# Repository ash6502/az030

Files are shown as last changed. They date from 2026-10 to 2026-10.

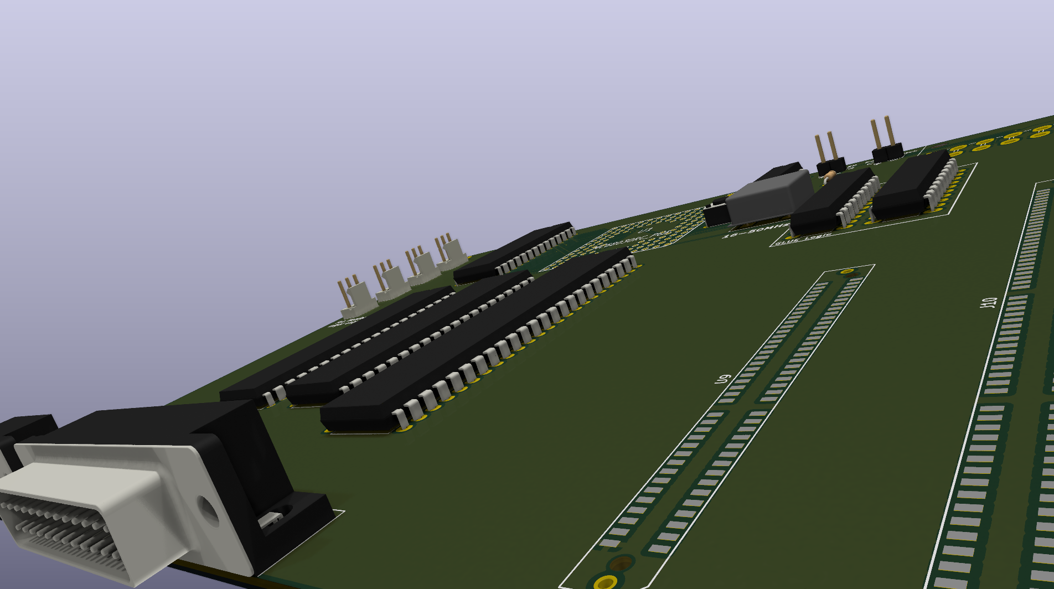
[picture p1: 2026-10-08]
kicad/main/exp2.png

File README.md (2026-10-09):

# az030 - a 68030-based homebrew computer
**! AI DISCLAIMER !**

Claude Code was used in the creation of this

# info

| Plan item | Status |
|---|---|
| 16–50 MHz clock | CPU clock generated in FPGA (25 MHz from a 50 MHz osc) |
| 128 MB – 1 GB RAM | 32 KB BRAM stand-in; SDRAM/DDR controller is next |
| Glue logic in FPGA | bus bridge, address decode, reset, UART, sysctrl |
| Video in FPGA | Address space reserved (VRAM `0xFD000000`, regs `0xFE003000`) |
| SCSI | Address space reserved (`0xFE002000`) |
| UNIX-like OS | Needs MMU → the 68030 (not 68EC030) was chosen for this |

## Memory map
| Address | Size | What |
|---|---|---|
| `0x0000_0000`  | 32 KB* | RAM (*for now). ROM overlays it at reset until SYSCTRL BOOT is written |
| `0xFD00_0000`  | – | VRAM (reserved) |
| `0xFE00_0000`  | 8 B | UART: `+0` DATA, `+4` STATUS (bit0 tx_ready, bit1 rx_valid) |
| `0xFE00_1000`  | 12 B | SYSCTRL: `+0` BOOT (any write drops overlay), `+4` ID, `+8` LEDS |
| `0xFE00_2000`  | – | SCSI (reserved) |
| `0xFE00_3000`  | – | Video registers (reserved) |
| `0xFFF0_0000`  | 16 KB  | Boot ROM (mirrored across 1 MB) |

Peripheral registers are **32-bit access only** (`move.l`). Unmapped addresses raise a bus error after 256 FPGA clocks.

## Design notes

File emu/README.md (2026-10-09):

# az030 emulator

An emulator for the az030 built on [m68k-rs](https://github.com/benletchford/m68k-rs).
It emulates a 68030 with an FPU (68881/68882), the memory map in `../MEM_MAP.md`, the UART
as your terminal, and an optional virtual SCSI bus.

```sh
cargo run --release                      # uses ./az030.toml
cargo run --release -- -c other.toml -v  # -v reports LED changes on stderr
cargo run --release -- --trace 200       # print the last 200 instructions (outside ROM) on exit
```

The UART connects to the terminal. **Ctrl-] q** quits, **Ctrl-] r** resets the machine, and
**Ctrl-] Ctrl-]** sends a literal Ctrl-]. Ctrl-C goes to the guest.

## Config (`az030.toml`)

| Key | Meaning |
|---|---|
| `machine.ram_size` | `"32K"`, `"128M"`, `"1G"`, or bytes. 4K–1G |
| `machine.clock_mhz` | Emulated clock, used to pace emulation (default 25) |
| `machine.throttle` | `false` runs as fast as possible |
| `machine.sysctrl_id` | Value of the SYSCTRL ID register (default `0x415A3330`, "AZ30") |
| `rom.file` | Raw boot ROM image, up to 1 MB, mirrored over `0xFFF00000+` |
| `scsi.enabled` | `false` leaves `0xFE002000` unmapped (bus error) |
| `timer.enabled` | `false` leaves `0xFE004000` unmapped (default `true`) |
| `scsi.host_id` | Host adapter ID (default 7) |
| `[[scsi.disk]]` | `id`, `image`, `read_only`, `create_size` |

Relative paths resolve against the config file's directory.

## Emulated hardware

* **RAM** at 0, sized from the config. At reset the ROM overlays it for reads (writes still
  reach RAM) until anything is written to SYSCTRL BOOT.
* **UART** at `0xFE000000`: `+0` DATA, `+4` STATUS (bit0 tx_ready, always set; bit1 rx_valid).
* **SYSCTRL** at `0xFE001000`: `+0` BOOT, `+4` ID, `+8` LEDS.
* **ROM** at `0xFFF00000`, mirrored across 1 MB. Writes are ignored.
* Peripheral registers accept 32-bit accesses only. Byte/word accesses to them and all
  accesses to unmapped space (including the reserved VRAM and video blocks) raise a bus error.

Not emulated yet: the VERA/video, PS/2 keyboard, the floppy, and Ethernet. None of them
have registers in the memory map.

## Timer / interrupt controller (`0xFE004000`)

Also emulator-defined, so a preemptive OS has a clock. It provides a periodic tick, a
microsecond counter, a wall-clock RTC and interrupt enables. Interrupts are
autovectored: the tick is IPL 6 (vector 30), UART receive is IPL 4 (vector 28).
Levels are re-evaluated once per millisecond of emulated time. Registers are 32-bit.

| Offset | R/W | Register | Meaning |
|---|-----|---|---|
| `0x00` | RW  | CTRL | bit0 tick enable |
| `0x04` | RW  | PERIOD | tick period in µs (100–1000000, default 10000 = 100 Hz) |
| `0x08` | RW  | STATUS | bit0 tick pending; write 1 to acknowledge |
| `0x0C` | R | USEC_LO  | µs since reset, low word (reading it latches USEC_HI) |
| `0x10` | R | USEC_HI  | high word |
| `0x14` | R | RTC | host wall clock, seconds since 1970-01-01 UTC |
| `0x18` | RW  | INTEN | bit0 tick → IPL 6, bit1 UART RX data → IPL 4 |
| `0x1C` | R | INTPEND  | bit0 tick, bit1 UART RX (pending and enabled) |
| `0x20` | W | POWER | write `0x504F4646` ("POFF") to power off (emulator exits) |
| `0x24` | R | ID | `0x54494D52` ("TIMR") |

## Virtual SCSI (`0xFE002000`)

The memory map only reserves this block, so the emulator defines a simple DMA host adapter
for it. Set the target, CDB and buffer, then write EXECUTE. The command finishes (DONE set)
before the write returns. Registers are 32-bit.

| Offset | R/W | Register | Meaning |
|---|-----|---|---|
| `0x00` | W | CMD | 1 EXECUTE, 2 BUS RESET, 3 CLEAR STATUS |
| `0x04` | R | STATUS | bit0 BUSY, bit1 DONE, bit2 NO TARGET, bit3 DMA ERROR, bits 15:8 SCSI status (0 GOOD, 2 CHECK CONDITION) |
| `0x08` | RW  | TARGET | bits 2:0 ID, bits 10:8 LUN |
| `0x0C` | RW  | DMA_ADDR | RAM address of the data buffer |
| `0x10` | RW  | DMA_LEN  | Buffer size in bytes |
| `0x14` | R | XFER | Bytes moved by the last command |
| `0x18` | RW  | CDB_LEN  | 6/10/12/16 |
| `0x1C` | R | ID | `0x53435349` ("SCSI") |
| `0x20`–`0x2F` | RW | CDB | CDB bytes 0–15, big-endian, four per register |

Disks are direct-access devices with 512-byte blocks. They support TEST UNIT READY,
REQUEST SENSE, INQUIRY, MODE SENSE(6), READ CAPACITY(10), READ/WRITE(6/10), VERIFY,
SYNCHRONIZE CACHE, START STOP UNIT, PREVENT ALLOW and FORMAT UNIT (a no-op). Any other
opcode returns CHECK CONDITION / ILLEGAL REQUEST.

## Boot disks

```sh
cargo run --release -- mkdisk disks/hello.img 1M --boot ../rom/examples/hello.bin --load 0x10000
```

This writes a boot block at LBA 0 (all fields big-endian), with the program from LBA 1 on:

| Offset | Field |
|---|---|
| `0x00` | `"AZ30BOOT"` |
| `0x08` | load address |
| `0x0C` | entry address (`--entry`, defaults to the load address) |
| `0x10` | program length in blocks |
| `0x14` | program length in bytes |

The boot ROM reads the program to the load address and calls the entry point with
`d0` = SCSI ID and `d1` = RAM size. See `../rom/boot.s` for the monitor commands and the
TRAP #15 system calls.

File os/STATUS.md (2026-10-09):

# az030 OS: work in progress

## Done and verified
- `lib/azas`: 68030/68882/PMMU assembler (vasm-style syntax, binary + ELF output).
  Assembles `rom/boot.bin` byte-for-byte; matches GNU as on a ~4000-instruction corpus
  (`tools/astest.py`).
- `lib/azld`: static ELF linker (archives/rlibs, GC sections, ELF exec or flat binary);
  compiles LLVM bitcode with a patched `llc` (`tools/src/bin/azld.rs`).
- `lib/rtasm`: asm runtime (mem*, 64-bit int helpers, FPU-backed float ABI) replacing
  compiler_builtins, which rustc compiles with its unpatched LLVM.
- Toolchain: local rust-src + LLVM 23.1.1 llc with M68k fixes (`toolchain/llvm-m68k-fixes.patch`):
  1. store of an extending load folded into a full-width mem-to-mem move
  2. frame-index + index register addressing dropped the index
  3. register copies clobbered CCR between compare and branch
  4. fastcc sret: callee popped a stack slot that was never pushed
- emulator: timer/IRQ block at 0xFE004000, `--trace`, `--stop-at`, `--dump`.
- `boot/boot.s` bootloader, `tools/src/bin/azmkdisk.rs` disk/azfs builder, `lib/azfs`, `lib/azsys`.

## In progress
- One known remaining codegen bug: Grisu exact float formatting (`{:.3}`) wrong.
  `llc -verify-machineinstrs` reports errors (illegal vregs for `MOVM16*_P` spills of DR8
  values, allocatable live-ins, undefined physregs, `AND32di` on address registers) —
  next lead.
- Kernel (`kernel/`): written and type-checks, never built/run yet.

## Not started
- Rust userland runtime + utilities, shell, nano-like editor, C / Rust-subset compilers,
  Makefile, disk image assembly, docs.

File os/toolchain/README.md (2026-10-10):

# Toolchain notes

The OS is written in Rust (plus 68k assembly) and cross-compiled with the stock
`rustc`, but two pieces are local:

* **rust-src** (downloaded by `make toolchain`) so `core` and `alloc` can be built for
  `m68k-unknown-none-elf` with `-Zbuild-std`.
* **A patched LLVM `llc`** (`build-llvm.sh`). LLVM's M68k back end is experimental and
  miscompiles ordinary Rust code, and rustc's LLVM cannot be patched in place. So rustc
  emits LLVM bitcode (`-C linker-plugin-lto`, see `os/.cargo/config.toml`) and our linker,
  azld, compiles it with the patched `llc` (cached by content hash).

Rust's `compiler_builtins` is always compiled by rustc's own (unpatched) LLVM, so the
routines it would provide (`memcpy`, 64/128-bit integer helpers, soft float) are
replaced by `lib/rtasm/*.s` (assembly; floats use the 68882) and `lib/azrt` (Rust,
compiled by the patched llc). azld lets definitions in plain objects override those in
archives, so the replacements win without touching rustc.

## LLVM M68k fixes (`llvm-m68k-fixes.patch`, against LLVM 23.1.1)

Each was found with the differential test in `os/tests/cgtest` (`make cgtest`), which
runs the same Rust code on the host and on the emulated 68030 and compares the output.

1. **Extending loads folded into memory-to-memory moves** (`isSafeStoreLoad`).
   `*u32_ptr = *u8_ptr as u32` became `move.l (src),(dst)`, copying 4 bytes.
2. **Index register dropped from frame-index addresses** (`hasIndexReg`, `SelectARID`,
   `SelectARI`). `buf[i] = x` for a stack array stored to `(d8,sp)` ignoring `i`.
3. **Register copies clobbering the condition codes** (`copyPhysReg`). A `move.l` into a
   data register sets N/Z; copies placed between a compare and its branch flipped the
   branch. CCR is now saved around such copies when it is live.
4. **fastcc struct returns popping a stack slot that was never pushed**
   (`LowerCall`/`LowerFormalArguments`). The callee overwrote the caller's `(sp)`.
5. **Sign/zero-extension pseudos allowed address-register destinations**
   (`MOV[SZ]Xd32d16`). Their expansion ANDs/EXTs the destination, which the encoder
   then emitted against the *data* register with the same number.
6. **32-bit `divs.l`/`divu.l` encoded with Dr = d0** (`MxDiMuOp_DD_Long`). The CPU
   wrote the remainder into d0, unknown to the register allocator. Dr now equals Dq.

`tools/flagcheck.py` (CCR hazards in a disassembly) and `llc -verify-machineinstrs`
were useful for finding them; azld honours `AZLD_OPT` and `AZLD_LLC_ARGS` (e.g.
`-opt-bisect-limit=N`) for debugging. llc is run with `-code-model=large` (absolute
addressing; LLVM's default assumes code and data within ±32 KB) and
`-function-sections` so unused code can be garbage collected.

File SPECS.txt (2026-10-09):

CPU: Motorola 68030 @ 16-50MHz
    ^-- also will have an FPU
RAM: 128MB-1GB SDRAM/DDR
Fixed Storage: Internal SCSI
Removable Storage: External SCSI (DB25) and a 1.44MB HD floppy drive
Planned Graphics: VERA, as found on the Commander X16
    ^-- for the emulator, it'll only emulate text-only video, like on old Data Terminals (or like a system like found in the Apple-1/Apple-II)
On-Board I/O (doesnt include the VERA I/O):
    RS232
    PS/2 Keyboard and Mouse 
        ^-- mouse unsupported in the emulator for obvious reasons if you have a reading level of at minimum of a 5th grader
    DB25 External SCSI
    Ethernet*
        ^-- depends on if i can implement it
    more soon i just havent come up with more I/O that would make sense
Audio: Built-In speakers and/or a headphone jack
    ^-- unsupported in the emulator

thats all for now, more specs are still TBD

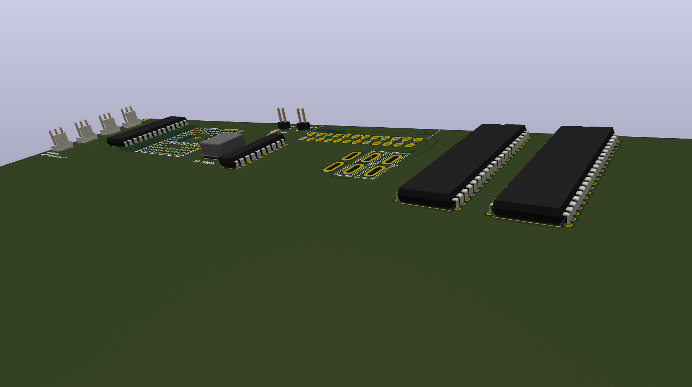
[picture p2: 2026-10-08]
kicad/main/exp1.png

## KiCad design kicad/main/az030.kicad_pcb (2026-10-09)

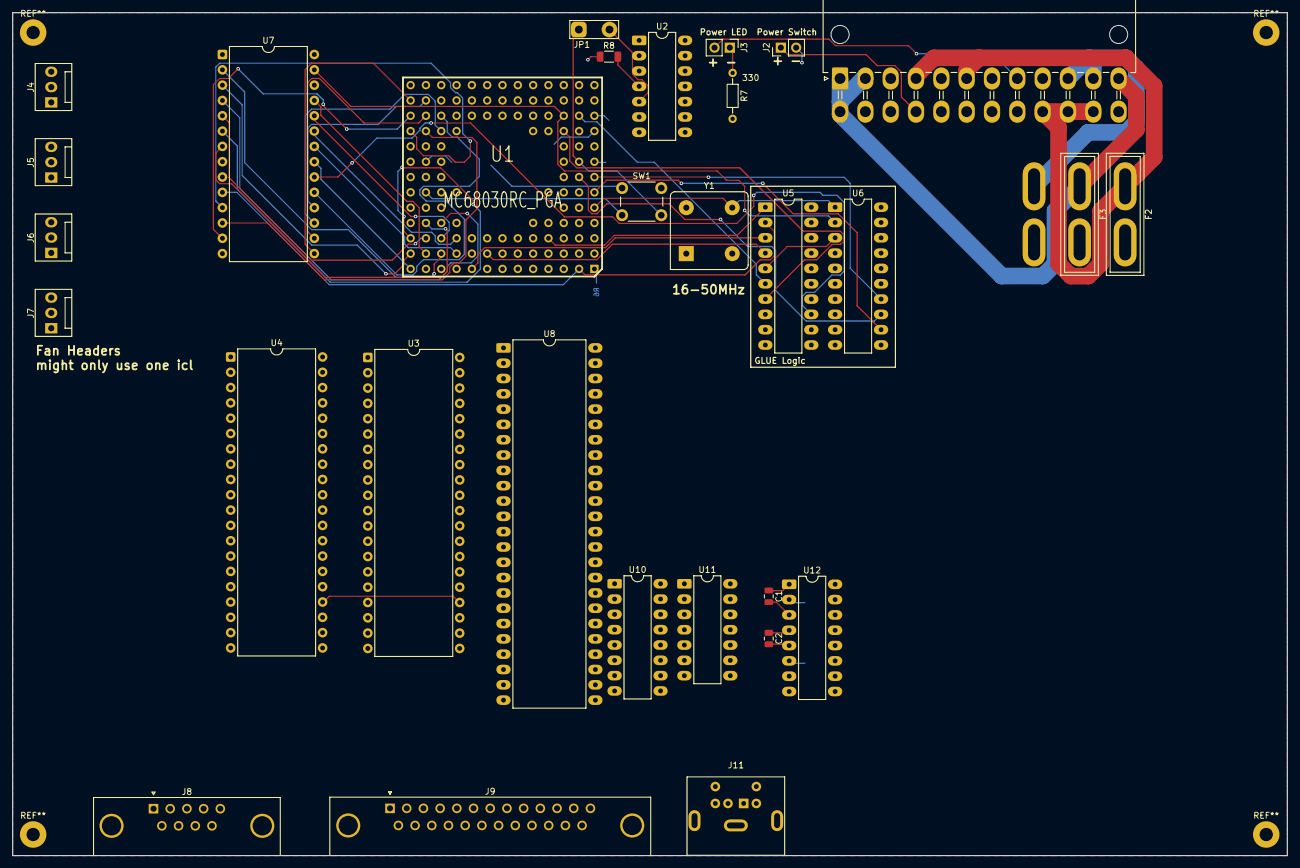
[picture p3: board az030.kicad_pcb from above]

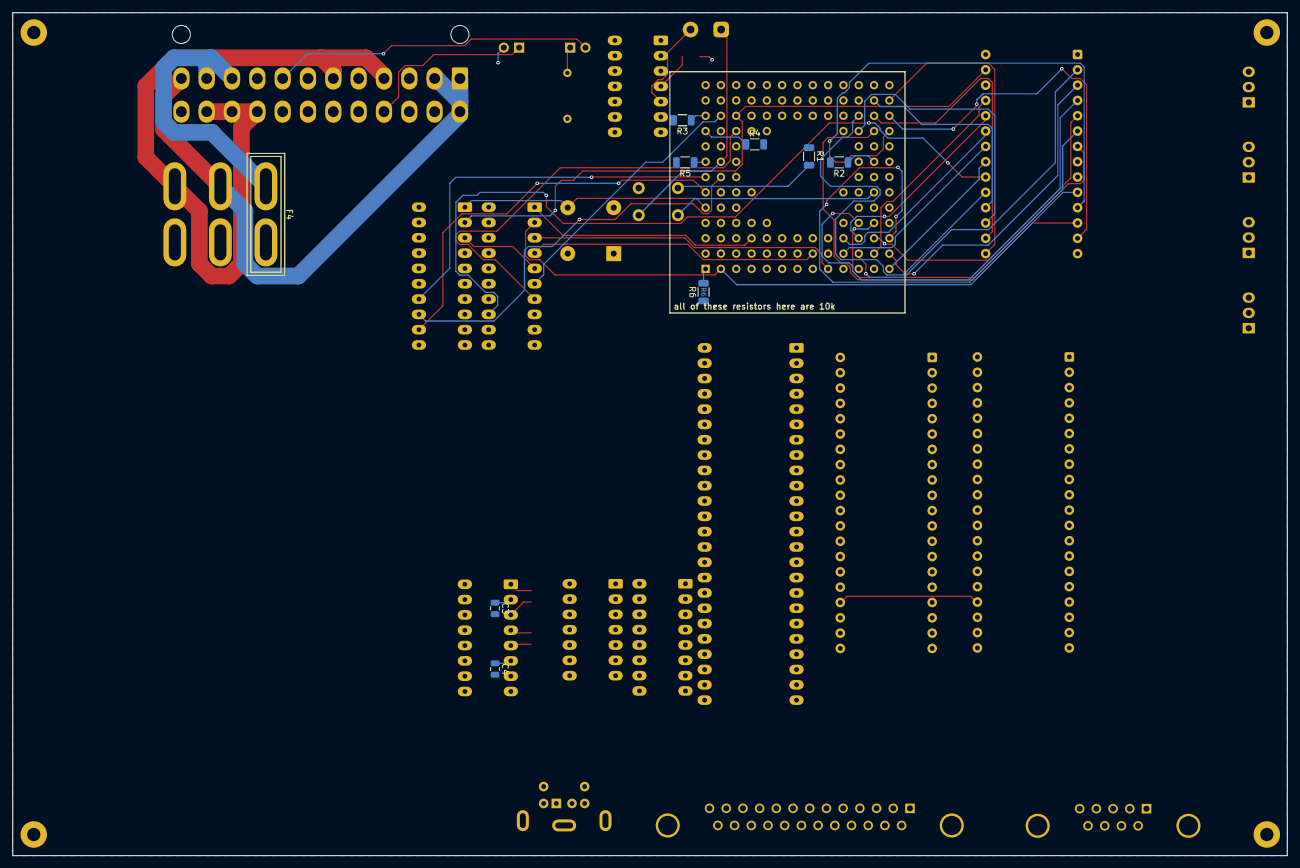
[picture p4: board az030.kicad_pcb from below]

Board: 4 copper layers, 211.4 x 139.8 mm, 39 parts (9 on the bottom side), 68 nets.

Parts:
C1, C2, C3, C4: 1u; C_0805_2012Metric
F2: 5a; Fuse_Blade_ATO_directSolder
F3, F4: 3a; Fuse_Blade_ATO_directSolder
J1: ATX-24; Molex_Mini-Fit_Jr_5569-24A2_2x12_P4.20mm_Horizontal
J2: Conn_01x02_Pin; PinHeader_1x02_P2.54mm_Vertical
J3: LED; PinHeader_1x02_P2.54mm_Vertical
J4, J5, J6, J7: Conn_01x03_Pin; FanPinHeader_1x03_P2.54mm_Vertical
J8: DE9_Pins_MountingHoles; DSUB-9_Pins_Horizontal_P2.77x2.84mm_EdgePinOffset4.94mm_Hou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
J9: DB25_Pins_MountingHoles; DSUB-25_Pins_Horizontal_P2.77x2.84mm_EdgePinOffset4.94mm_Ho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
J11: PS/2; Connector_Mini-DIN_Female_6Pin_2rows
JP1: RUN; TestPoint_2Pads_Pitch5.08mm_Drill1.3mm
R1, R2, R3, R4, R5, R6, R8: 10k; R_1206_3216Metric
R7: 330; R_Axial_DIN0204_L3.6mm_D1.6mm_P7.62mm_Horizontal
SW1: SW_Push; SW_PUSH_6mm
U1: MC68030RC_PGA; MC68030
U2: 74HC74; DIP-14_W7.62mm_LongPads
U3, U4: W65C22SxP; DIP-40_W15.24mm
U5, U6: GAL16V8; DIP-20_W7.62mm_LongPads
U7: CY62256-70PC; DIP-28_W15.24mm
U8: DIP-48_W15.24mm_LongPads
U10: 74AHC595; DIP-16_W7.62mm_LongPads
U11: 74AHC04; DIP-14_W7.62mm_LongPads
U12: MAX232; DIP-16_W7.62mm_LongPads
Y1: CXO_DIP8; Oscillator_DIP-8_LargePads

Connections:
+5V: F2.2, J11.4, R1.1, R2.2, R3.2, R4.2, R5.2, R6.1, R8.1, U1.C6 (VCC), U1.D4 (VCC), U1.D10 (VCC), U1.F2 (VCC), U1.F11 (VCC), U1.H3 (VCC), U1.H11 (VCC), U1.H13 (IPL0), U1.K4 (VCC), U1.K10 (VCC), U1.L6 (VCC), U2.14 (VCC), U3.20 (VCC), U4.20 (VCC), U5.20 (V_{CC}), U6.20 (V_{CC}), U7.28 (VCC), U10.10 (~SRCLR), U10.16 (VCC), U11.14 (VCC), U12.16 (VCC), Y1.8 (Vcc)
+12V: F4.2, J4.2, J5.2, J6.2, J7.2
/CPU/A0: U1.A2 (A0), U5.2 (I_{1}), U7.10 (A0)
/CPU/A1: U1.C4 (A1), U5.1 (I_{0}), U7.9 (A1)
/CPU/A2: U1.D13 (A2), U7.8 (A2)
/CPU/A3: U1.D12 (A3), U7.7 (A3)
/CPU/A4: U1.C13 (A4), U7.6 (A4)
/CPU/A5: U1.C12 (A5), U7.5 (A5)
/CPU/A6: U1.D11 (A6), U7.4 (A6)
/CPU/A7: U1.B13 (A7), U7.3 (A7)
/CPU/A8: U1.B12 (A8), U7.25 (A8)
/CPU/A9: U1.C11 (A9), U7.24 (A9)
/CPU/A10: U1.A13 (A10), U7.21 (A10)
/CPU/A11: U1.C10 (A11), U7.23 (A11)
/CPU/A12: U1.B11 (A12), U7.2 (A12)
/CPU/A13: U1.A12 (A13), U7.26 (A13)
/CPU/A14: U1.B10 (A14), U7.1 (A14), U7.22 (~OE)
/CPU/A19: U1.A9 (A19), U5.3 (I_{2})
/CPU/A20: U1.B8 (A20), U5.4 (I_{3})
/CPU/A25: U1.B6 (A25), U5.5 (I_{4}), U6.3 (I_{2})
/CPU/D0: U1.K13 (D0), U7.11 (Q0)
/CPU/D1: U1.K12 (D1), U7.12 (Q1)
/CPU/D2: U1.L13 (D2), U7.13 (Q2)
/CPU/D3: U1.M13 (D3), U7.15 (Q3)
/CPU/D4: U1.L12 (D4), U7.16 (Q4)
/CPU/D5: U1.K11 (D5), U7.17 (Q5)
/CPU/D6: U1.M12 (D6), U7.18 (Q6)
/CPU/D7: U1.L11 (D7), U7.19 (Q7)
/Peripheral Management/R~W: U3.22 (R/~W), U4.22 (R/~W)
AS: U1.J2 (AS), U5.8 (I_{7})
CLOCK: U1.E1 (CLKIN), U6.1 (I_{0}), Y1.5 (OUT)
DSACK0: U1.F1 (DSACK0), U6.12 (F_{0})
DSACK1: U1.G2 (DSACK1), U6.13 (F_{1})
ECS: U1.M2 (ECS), U2.3 (C)
GND: C3.2, C4.2, J1.3 (GND), J1.5 (GND), J1.7 (GND), J1.15 (GND), J1.17 (GND), J1.18 (GND), J1.19 (GND), J1.24 (GND), J2.2, J4.1, J5.1, J6.1, J7.1, J11.3, R7.2, U1.C5 (GND), U1.C7 (GND), U1.C9 (GND), U1.E2 (AVEC), U1.E3 (GND), U1.E11 (GND), U1.F3 (GND), U1.G3 (GND), U1.G11 (GND), U1.J3 (GND), U1.J11 (GND), U1.L5 (GND), U1.L7 (GND), U1.L8 (GND), U1.L9 (GND), U2.7 (GND), U3.1 (VSS), U4.1 (VSS), U5.10 (GND), U6.10 (GND), U7.14 (GND), U10.8 (GND), U10.13 (~OE), U11.7 (GND), U12.15 (GND), Y1.4 (GND)
unnamed: F2.1, J1.4 (+5V), J1.6 (+5V), J1.21 (+5V), J1.22 (+5V), J1.23 (+5V)
unnamed: F3.1, J1.1 (+3.3V), J1.2 (+3.3V), J1.12 (+3.3V), J1.13 (+3.3V)
unnamed: F4.1, J1.10 (+12V), J1.11 (+12V)
unnamed: J1.16 (PS_ON#), J2.1
unnamed: J1.8 (PWR_OK), J3.2
unnamed: J3.1, R7.1
unnamed: JP1.1 (A), U1.H2 (HLT)
unnamed: JP1.2 (B), U2.5 (Q)
unnamed: R5.1, U1.H1 (BERR)
unnamed: R6.2, U1.A1 (BR)
unnamed: R4.1, U1.K1 (CBREQ)
unnamed: R2.1, U1.H12 (CDIS)
unnamed: R3.1, U1.L1 (CIIN)
unnamed: SW1.2, U1.F12 (RESET)
unnamed: U2.2 (D), U2.6 (~Q)
unnamed: R8.2, U2.4 (~S)
unnamed: U10.12 (RCLK), U11.6
unnamed: U10.11 (SRCLK), U11.2, U11.3
unnamed: U11.4, U11.5
unnamed: C1.1, U12.1 (C1+)
unnamed: C1.2, U12.3 (C1-)
unnamed: C2.1, U12.4 (C2+)
unnamed: C2.2, U12.5 (C2-)
unnamed: C3.1, U12.2 (VS+)
unnamed: C4.1, U12.6 (VS-)
PS/2 Clock: J11.5, U11.1
PS/2 Data: J11.1, U10.14 (SER)
RAM0: U5.13 (F_{1}), U7.20 (~CS)
RESET: R1.2, SW1.1, U2.1 (~R), U8.2 (RST_2)
R~W: U1.L3 (R_W), U6.2 (I_{1}), U7.27 (~WE)
SIZ0: U1.L2 (SIZ0), U5.6 (I_{5})
SIZ1: U1.K3 (SIZ1), U5.7 (I_{6})
STERM: U1.G1 (STERM), U6.14 (F_{2})

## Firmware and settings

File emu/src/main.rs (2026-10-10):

mod bus;
mod config;
mod scsi;
mod terminal;
mod timer;

use bus::Bus;
use config::Config;
use m68k::{CpuCore, CpuType};
use std::path::PathBuf;
use std::process::ExitCode;
use std::sync::mpsc::TryRecvError;
use std::time::{Duration, Instant};

/// Ctrl-] : emulator escape key (like telnet).
const ESCAPE: u8 = 0x1D;

const USAGE: &str = "\
az030 emulator

usage:
  az030-emu [-c CONFIG] [-v] [--max-cycles N]
  az030-emu mkdisk IMAGE SIZE [--boot PROGRAM.bin --load ADDR [--entry ADDR]]

options:
  -c, --config FILE   machine config (default: az030.toml)
  -v, --verbose       report LED changes and CPU halts on stderr
  --max-cycles N      stop after N CPU cycles (for scripted runs)
  --trace N           keep the last N executed instructions (outside ROM) and print
                      them on exit
  --stop-at ADDR      stop when the PC reaches ADDR (hex; useful with --trace)
  --dump ADDR:LEN     hex-dump physical memory when the emulator stops

console keys:
  Ctrl-] q   quit           Ctrl-] r   reset
  Ctrl-] Ctrl-]   send a literal Ctrl-]
";

fn main() -> ExitCode {
    let args: Vec<String> = std::env::args().skip(1).collect();
    let result = if args.first().map(String::as_str) == Some("mkdisk") {
        mkdisk(&args[1..])
    } else {
        run(&args)
    };
    match result {
        Ok(()) => ExitCode::SUCCESS,
        Err(e) => {
            eprintln!("az030-emu: {e}");
            ExitCode::FAILURE
        }
    }
}

fn parse_num(s: &str) -> Result<u64, String> {
    config::parse_size(s)
}

fn run(args: &[String]) -> Result<(), String> {
    let mut config_path = PathBuf::from("az030.toml");
    let mut verbose = false;
    let mut max_cycles: Option<u64> = None;
    let mut trace_len = 0usize;
    let mut stop_at: Option<u32> = None;
    let mut dumps: Vec<(u32, u32)> = Vec::new();
    let mut it = args.iter();
    while let Some(a) = it.next() {
        match a.as_str() {
            "-c" | "--config" => {
                config_path = it.next().ok_or("--config needs a file")?.into();
            }
            "-v" | "--verbose" => verbose = true,
            "--max-cycles" => {
                max_cycles = Some(parse_num(it.next().ok_or("--max-cycles needs N")?)?);
            }
            "--dump" => {
                let a = it.next().ok_or("--dump needs ADDR:LEN")?;
                let (addr, len) = a.split_once(':').ok_or("--dump needs ADDR:LEN")?;
                let addr = u32::from_str_radix(addr.trim_start_matches("0x"), 16).map_err(|_| "bad --dump address")?;
                dumps.push((addr, parse_num(len)? as u32));
            }
            "--stop-at" => {
                let a = it.next().ok_or("--stop-at needs an address")?;
                let a = a.trim_start_matches("0x");
                stop_at = Some(u32::from_str_radix(a, 16).map_err(|_| "bad --stop-at address")?);
            }
            "--trace" => {
                trace_len = parse_num(it.next().ok_or("--trace needs N")?)? as usize;
            }
            "-h" | "--help" => {
                print!("{USAGE}");
                return Ok(());
            }
            _ => return Err(format!("unknown argument {a:?}\n\n{USAGE}")),
        }
    }

    let cfg = Config::load(&config_path)?;
    let rom = std::fs::read(&cfg.rom.file)
        .map_err(|e| format!("cannot read ROM {}: {e}", cfg.rom.file.display()))?;
    if rom.is_empty() || rom.len() as u64 > config::MAX_ROM {
        return Err(format!("ROM image must be 1 byte to 1 MB (got {})", rom.len()));
    }
    let scsi = if cfg.scsi.enabled { Some(scsi::Scsi::new(&cfg.scsi.disks)?) } else { None };
    let timer = cfg.timer.enabled.then(timer::Timer::new);
    let mut bus = Bus::new(cfg.machine.ram_size.0 as usize, rom, cfg.machine.sysctrl_id, scsi, timer);

    let mut cpu = CpuCore::new();
    cpu.set_cpu_type(CpuType::M68030);
    cpu.fpu_present = true;
    cpu.reset(&mut bus);

    let raw = terminal::RawMode::enable();
    if raw.is_tty() {
        eprint!("az030: {} RAM, {} MHz. Ctrl-] q to quit, Ctrl-] r to reset.\r\n",
            human(cfg.machine.ram_size.0), cfg.machine.clock_mhz);
    }
    let input = terminal::spawn_input();

    // Run in 1 ms slices of emulated time, servicing the console in between.
    let clock_hz = cfg.machine.clock_mhz * 1e6;
    let slice = ((clock_hz / 1000.0) as i32).max(100);
    let start = Instant::now();
    let mut total_cycles: u64 = 0;
    let mut escape = false;
    let mut input_open = true;
    let mut was_halted = false;
    let mut trace: std::collections::VecDeque<(u32, u16, [u32; 16])> = Default::default();

    'outer: loop {
        if cpu.is_halted() {
            if !was_halted && verbose {
                eprint!("\r\n[az030] CPU halted (double bus fault) at PC={:08X}\r\n", cpu.pc);
            }
            was_halted = true;
            total_cycles += slice as u64;
        } else if trace_len > 0 {
            let mut done = 0i32;
            while done < slice && !cpu.is_halted() {
                if stop_at == Some(cpu.pc) {
                    eprint!("\r\n[az030] reached {:08X}\r\n", cpu.pc);
                    break 'outer;
                }
                // ROM code is not traced, so the log shows the program, not the monitor.
                if cpu.pc < 0xFFF0_0000 {
                    if trace.len() == trace_len {
                        trace.pop_front();
                    }
                    trace.push_back((cpu.pc, cpu.get_sr(), cpu.dar));
                }
                // a handler that declines everything: traps take their real exceptions
                struct NoHle;
                impl m68k::HleHandler for NoHle {}
                done += match cpu.step_with_hle_handler(&mut bus, &mut NoHle) {
                    m68k::StepResult::Ok { cycles } => cycles.max(1),
                    _ => 4,
                };
            }
            total_cycles += done as u64;
        } else {
            total_cycles += cpu.execute(&mut bus, slice).max(0) as u64;
        }
        bus.flush_tx();

        if let Some(t) = &mut bus.timer {
            t.advance((total_cycles as f64 / cfg.machine.clock_mhz) as u64);
            if t.power_off {
                break 'outer;
            }
        }
        cpu.set_irq(bus.irq_level());

        if bus.leds_changed && verbose {
            eprint!("\r\n[az030] LEDS = {:08b}\r\n", bus.leds & 0xFF);
        }
        bus.leds_changed = false;

        while input_open {
            match input.try_recv() {
                Ok(b) if escape => {
                    escape = false;
                    match b {
                        b'q' | b'Q' => break 'outer,
                        b'r' | b'R' => {
                            eprint!("\r\n[az030] reset\r\n");
                            bus.reset();
                            cpu.reset(&mut bus);
                            was_halted = false;
                        }
                        ESCAPE => bus.uart_rx.push_back(ESCAPE),
                        _ => eprint!("\r\n[az030] Ctrl-] then: q quit, r reset\r\n"),
                    }
                }
                Ok(ESCAPE) if raw.is_tty() => escape = true,
                Ok(b) => bus.uart_rx.push_back(b),
                Err(TryRecvError::Empty) => break,
                Err(TryRecvError::Disconnected) => input_open = false,
            }
        }

        if max_cycles.is_some_and(|m| total_cycles >= m) {
            break;
        }
        if cfg.machine.throttle {
            let target = Duration::from_secs_f64(total_cycles as f64 / clock_hz);
            let now = start.elapsed();
            if target > now {
                std::thread::sleep(target - now);
            }
        }
    }
    bus.flush_tx();
    drop(raw);
    for &(addr, len) in &dumps {
        for row in (0..len).step_by(16) {
            let a = addr.wrapping_add(row) as usize;
            let bytes: Vec<String> =
                (0..16).map(|i| bus.ram.get(a + i).map_or("--".into(), |b| format!("{b:02X}"))).collect();
            eprintln!("{:08X}: {}", a, bytes.join(" "));
        }
    }
    for (pc, sr, r) in &trace {
        eprintln!(
            "{pc:08X} SR={sr:04X} D={:08X} {:08X} {:08X} {:08X} {:08X} {:08X} {:08X} {:08X} A={:08X} {:08X} {:08X} {:08X} {:08X} {:08X} {:08X} {:08X}",
            r[0], r[1], r[2], r[3], r[4], r[5], r[6], r[7], r[8], r[9], r[10], r[11], r[12], r[13], r[14], r[15]
        );
    }
    if verbose {
        eprintln!("\n[az030] stopped after {total_cycles} cycles, PC={:08X}", cpu.pc);
    }
    Ok(())
}

fn human(n: u64) -> String {
    match n {
        n if n >= 1 << 30 && n % (1 << 30) == 0 => format!("{}G", n >> 30),
        n if n >= 1 << 20 && n % (1 << 20) == 0 => format!("{}M", n >> 20),
        n if n % (1 << 10) == 0 => format!("{}K", n >> 10),
        n => format!("{n} bytes"),
    }
}

/// Create a raw SCSI disk image, optionally with a program the boot ROM can load.
///
/// Boot block (LBA 0) layout, all big-endian:
///   0x00  "AZ30BOOT"
///   0x08  load address
///   0x0C  entry address
///   0x10  program length in 512-byte blocks (program starts at LBA 1)
///   0x14  program length in bytes
fn mkdisk(args: &[String]) -> Result<(), String> {
    let mut pos = Vec::new();
    let (mut boot, mut load, mut entry) = (None, None, None);
    let mut it = args.iter();
    while let Some(a) = it.next() {
        match a.as_str() {
            "--boot" => boot = Some(PathBuf::from(it.next().ok_or("--boot needs a file")?)),
            "--load" => load = Some(parse_num(it.next().ok_or("--load needs an address")?)?),
            "--entry" => entry = Some(parse_num(it.next().ok_or("--entry needs an address")?)?),
            _ => pos.push(a.clone()),
        }
    }
    let [image, size] = pos.as_slice() else { return Err(USAGE.into()) };
    let size = parse_num(size)?;
    if size % scsi::BLOCK != 0 || size < 2 * scsi::BLOCK {
        return Err("disk size must be a multiple of 512 and at least 1K".into());
    }
    let mut disk = vec![0u8; size as usize];
    if let Some(boot) = boot {
        let prog = std::fs::read(&boot).map_err(|e| format!("{}: {e}", boot.display()))?;
        let load = load.ok_or("--boot requires --load")? as u32;
        let entry = entry.map_or(load, |e| e as u32);
        let blocks = prog.len().div_ceil(scsi::BLOCK as usize);
        if (1 + blocks) as u64 * scsi::BLOCK > size {
            return Err("program does not fit on the disk".into());
        }
        disk[0..8].copy_from_slice(b"AZ30BOOT");
        disk[8..12].copy_from_slice(&load.to_be_bytes());
        disk[12..16].copy_from_slice(&entry.to_be_bytes());
        disk[16..20].copy_from_slice(&(blocks as u32).to_be_bytes());
        disk[20..24].copy_from_slice(&(prog.len() as u32).to_be_bytes());
        disk[512..512 + prog.len()].copy_from_slice(&prog);
    }
    std::fs::write(image, &disk).map_err(|e| format!("{image}: {e}"))?;
    println!("wrote {image} ({})", human(size));
    Ok(())
}

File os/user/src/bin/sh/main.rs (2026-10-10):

//! sh: the az030 command interpreter.
//!
//! A POSIX-style shell: pipelines, lists, `&&`/`||`, subshells and groups, `if`,
//! `while`/`until`, `for`, `case`, functions, here-documents, parameter and
//! arithmetic expansion, command substitution, globbing, aliases, job control and
//! an interactive line editor with history and tab completion.
//!
//!     sh                      interactive (if stdin is a terminal)
//!     sh -c 'cmds' [arg0 args]
//!     sh script [args]
//!     sh -l / -sh             login shell: reads /etc/profile and ~/.profile first

#![no_std]
#![no_main]

extern crate alloc;

mod arith;
mod builtins;
mod exec;
mod expand;
mod parse;

use parse::{Node, Parser};
use rt::io::{self, Fd};
use rt::prelude::*;
use rt::process::ExitStatus;
use rt::readline::{Editor, Line};
use rt::signal::{self, Handler};

rt::main!(main);

#[derive(Clone)]
pub struct Var {
    pub value: String,
    pub exported: bool,
    pub readonly: bool,
}

#[derive(Clone, Copy, PartialEq, Eq, Debug)]
pub enum Flow {
    None,
    Break(u32),
    Continue(u32),
    Return,
    Exit(i32),
}

pub struct Job {
    pub id: u32,
    pub pgid: u32,
    pub pids: Vec<u32>,
    pub status: Vec<Option<ExitStatus>>,
    pub stopped: bool,
    pub text: String,
}

impl Job {
    pub fn done(&self) -> bool {
        self.status.iter().all(|s| s.is_some_and(|s| !s.stopped()))
    }
    pub fn last_status(&self) -> i32 {
        self.status.last().copied().flatten().map(|s| s.shell_code()).unwrap_or(0)
    }
}

pub struct Shell {
    pub vars: BTreeMap<String, Var>,
    pub params: Vec<String>,
    pub arg0: String,
    pub status: i32,
    /// status of the last command substitution in the current command
    pub subst_status: Option<i32>,
    pub pid: u32,
    pub last_bg: u32,
    pub funcs: BTreeMap<String, Rc<Node>>,
    pub aliases: BTreeMap<String, String>,
    pub jobs: Vec<Job>,
    pub interactive: bool,
    pub job_control: bool,
    /// this process is a forked child of the shell (subshell, pipeline element)
    pub in_child: bool,
    pub shell_pgid: u32,
    pub opt_errexit: bool,
    pub opt_xtrace: bool,
    pub opt_noglob: bool,
    pub opt_nounset: bool,
    pub flow: Flow,
    pub loop_depth: u32,
    pub func_depth: u32,
    /// inside a condition (if/while test, left of && ||, after !): no errexit
    pub cond_depth: u32,
    /// saved variables for `local`, one frame per function call
    pub locals: Vec<Vec<(String, Option<Var>)>>,
    pub editor: Editor,
    pub hostname: String,
    pub history_file: Option<String>,
    pub saved_termios: Option<rt::term::Termios>,
}

impl Shell {
    fn new() -> Shell {
        let mut vars = BTreeMap::new();
        for (k, v) in rt::env::vars() {
            vars.insert(k, Var { value: v, exported: true, readonly: false });
        }
        let hostname = rt::fs::read_to_string("/etc/hostname").map(|s| s.trim().into()).unwrap_or_else(|_| "az030".into());
        Shell {
            vars,
            params: Vec::new(),
            arg0: "sh".into(),
            status: 0,
            subst_status: None,
            pid: rt::process::id(),
            last_bg: 0,
            funcs: BTreeMap::new(),
            aliases: BTreeMap::new(),
            jobs: Vec::new(),
            interactive: false,
            job_control: false,
            in_child: false,
            shell_pgid: 0,
            opt_errexit: false,
            opt_xtrace: false,
            opt_noglob: false,
            opt_nounset: false,
            flow: Flow::None,
            loop_depth: 0,
            func_depth: 0,
            cond_depth: 0,
            locals: Vec::new(),
            editor: Editor::new(),
            hostname,
            history_file: None,
            saved_termios: None,
        }
    }

    pub fn get_var(&self, name: &str) -> Option<String> {
        self.vars.get(name).map(|v| v.value.clone())
    }

    pub fn set_var(&mut self, name: &str, value: &str) -> Result<(), String> {
        match self.vars.get_mut(name) {
            Some(v) if v.readonly => return Err(format!("{name}: readonly variable")),
            Some(v) => v.value = value.into(),
            None => {
                self.vars.insert(name.into(), Var { value: value.into(), exported: false, readonly: false });
            }
        }
        if name == "PATH" {
            rt::env::set_var("PATH", value);
        }
        Ok(())
    }

    pub fn unset_var(&mut self, name: &str) -> Result<(), String> {
        if self.vars.get(name).is_some_and(|v| v.readonly) {
            return Err(format!("{name}: readonly variable"));
        }
        self.vars.remove(name);
        Ok(())
    }

    pub fn export(&mut self, name: &str) {
        self.vars.entry(name.into()).or_insert(Var { value: String::new(), exported: true, readonly: false }).exported = true;
    }

    /// The environment for a new program.
    pub fn environ(&self) -> Vec<String> {
        self.vars.iter().filter(|(_, v)| v.exported).map(|(k, v)| format!("{k}={}", v.value)).collect()
    }

    pub fn error(&self, msg: &str) {
        if self.interactive || self.arg0 == "sh" || self.arg0 == "-sh" {
            eprintln!("sh: {msg}");
        } else {
            eprintln!("{}: {msg}", self.arg0);
        }
    }

    /// Parse and run source text; used for -c, scripts, eval and `.`.
    pub fn run_source(&mut self, src: &str) -> i32 {
        let aliases = self.aliases.clone();
        let mut p = Parser::new(src, true, Some(&aliases));
        loop {
            match p.next_command() {
                Ok(Some(n)) => {
                    self.exec(&n);
                    if self.flow != Flow::None {
                        break;
                    }
                }
                Ok(None) => break,
                Err(parse::Error::Syntax(e)) => {
                    self.error(&e);
                    self.status = 2;
                    if !self.interactive {
                        self.flow = Flow::Exit(2);
                    }
                    break;
                }
                Err(parse::Error::Incomplete) => {
                    self.error("unexpected end of file");
                    self.status = 2;
                    break;
                }
            }
        }
        self.status
    }

    pub fn run_file(&mut self, path: &str) -> Result<i32, String> {
        let text = rt::fs::read_to_string(path).map_err(|e| format!("{path}: {e}"))?;
        let text = if text.starts_with("#!") { text.split_once('\n').map(|x| x.1).unwrap_or("").into() } else { text };
        Ok(self.run_source(&text))
    }
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

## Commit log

2026-10-02 add wip pcb
    [az030.kicad_pcb, az030.kicad_sch]
2026-10-03 move main pcb to its own folder
    [az030.kicad_pcb, az030.kicad_sch]
2026-10-06 update pcb
    [az030.kicad_pcb, az030.kicad_sch, cpu.kicad_sch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]
2026-10-07 so much shit done holy
    [az030.kicad_pcb, az030.kicad_sch, cpu.kicad_sch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]
2026-10-09 remove some stuff
    [az030.kicad_pcb, az030.kicad_sch, biRAM.kicad_sch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]
2026-10-09 Add Rust emulator and boot ROM
    emu/: az030 emulator built on the m68k crate (m68k-rs). Emulates a
    68030 + FPU with the MEM_MAP.md layout: RAM with the reset-time ROM
    overlay, UART as the host terminal, SYSCTRL, mirrored boot ROM, and bus
    errors for unmapped space and non-32-bit peripheral accesses. A TOML
    config sets RAM size, ROM file, clock/throttle and virtual SCSI disks.
    The SCSI block at 0xFE002000 is emulator-defined (DMA-style host
    adapter, documented in emu/README.md). `mkdisk` builds bootable images.
    rom/: 16 KB boot ROM/monitor in 68030 assembly (vasm). Sizes RAM,
    detects the FPU and SCSI, autoboots AZ30BOOT disks, and provides a
    monitor (dump/write, S-record load, disk read/write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
    [bus.rs, main.rs]
2026-10-10 Fix the m68k code generator; add a differential codegen test
    LLVM's experimental M68k back end miscompiled ordinary Rust code. Add
    os/tests/cgtest, which runs the same Rust code natively and on the
    emulated 68030 and diffs the output (`make cgtest`), and fix everything
    it found: two more back-end bugs (address-register destinations for the
    extension pseudos, and 32-bit divides clobbering d0 with the remainder),
    128-bit division (now in lib/azrt, compiled by the patched llc, behind
    asm stubs), and double rounding in the FPU-based float routines. The
    test now passes.
    Also adds os/Makefile, toolchain/build-llvm.sh, toolchain/README.md
    documenting all six LLVM fixes, the azbuild helper for buil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
    [main.rs]
2026-10-10 emu: vendor the m68k crate with a fixed 68030 TTx register layout
    The crate decoded TT0/TT1 with the 68040 field layout, so enabling the
    MMU with transparent translation (as the OS kernel does) faulted at once.
    Vendor it under emu/vendor with the 68030 layout (CI bit 10, R/W 9, RWM 8,
    FC base 6:4, FC mask 2:0) and tests.
    Also make --trace use step_with_hle_handler with a no-op handler, so
    TRAP instructions are taken instead of being reported to the caller.
    [main.rs]
2026-10-10 kernel: build with azbuild/azrt, fix init start-up
    - Link the kernel through azbuild with the assembly runtime (mem.s,
    int.s) and azrt instead of the miscompiled compiler_builtins.
    - start_init: make process 1 current before opening /dev/console, and
    open it with O_NOCTTY so the sessions init starts can take the console
    as their controlling terminal.
    [main.rs]
2026-10-10 os: user runtime, init, login, sh and the core utilities
    - user/: the rt runtime library (system calls, heap, buffered stdio,
    files, processes, signals, termios, time, getopt, globbing, regular
    expressions, SHA-256, user database, line editor) and the programs.
    - init runs /etc/rc and keeps a login session on the console.
    - sh: a POSIX-style shell with pipelines, lists, if/while/until/for/case,
    functions, here-documents, parameter/arithmetic expansion, command
    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
2026-10-11 os: add the edit screen editor and the as/ld/ar binary tools
    - edit: a nano-style editor (cut/paste, search and replace, mark, undo/redo,
    go to line, justify, bracket matching, auto-indent, line numbers) with
    syntax highlighting for C, assembly, shell and Rust; redraws only the
    rows that change.
    - as, ld, ar: front ends for the azas and azld crates, which already build
    for the target.
    - /usr/src/examples/hello.s; cat -T/-A show tabs.
    - Use the AZ/UX name in the kernel banner, uname -v and the motd.
    - emutest: raw and sleep script commands for full-screen programs.
2026-10-11 os: add the azcc C compiler, libc and /bin/cc
    - lib/azcc: a no_std C compiler (most of C99: full declarator syntax,
    structs/unions with bit-fields, enums, typedefs, initializers with
    designators, compound literals, variadic functions, long long, float and
    double on the 68882, switch jump tables, statement expressions) with a
    preprocessor (function-like and variadic macros, # and ##, #if/#elif
    with defined, #include search paths, #pragma once). It emits azas
    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
2026-10-11 os: make, man, dmesg, docs; faster on-OS compiles
    New programs and docs
    - make: POSIX make with GNU extensions (pattern and suffix rules, := ?= +=,
    conditionals, include, functions such as wildcard/patsubst/foreach/shell,
    built-in rules for C and assembly).
    - man with /usr/share/man: section 1 pages are generated from each program's
    doc comment (tools/genman.py); hand-written pages for intro, sh, edit, cc,
    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
2026-10-15 more stuff
    added support for the VERA module in the emulator
    also re-doing the PCB
2026-10-16 gonna see if i can switch back to linux
